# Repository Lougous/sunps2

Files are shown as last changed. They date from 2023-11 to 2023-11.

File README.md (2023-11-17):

This project allows the use of PS/2 keyboard and mouse with SUN stations fitted with proprietary 8 pins mini-DIN connector.

It is based on a PIC24FJ48GA002 microcontroller, an absolute overkill, and quite inappropriate as it cannot run under 5V power input - but I got this part in stock. I used a 74HC00 NAND gates to invert serial link signals (SUN serial protocol has negative logic) as well as 3.3V to 5V level shifter. PIC's inputs are 5V tolerant.

Resource usage in the microcontroller:
 * 2 externals interrupts
 * 1 internal timer with interrupt
 * 2 UARTs
 * a very few bytes of RAM and ~1k instructions

features and limitations:
 * keyboard layout is configured at compilation (see SUN_LAYOUT #define in main.c)
 * keyboard LED driving is not implemented
 * F12 key is mapped to SUN STOP key - handy to enter openboot prompt with STOP-A

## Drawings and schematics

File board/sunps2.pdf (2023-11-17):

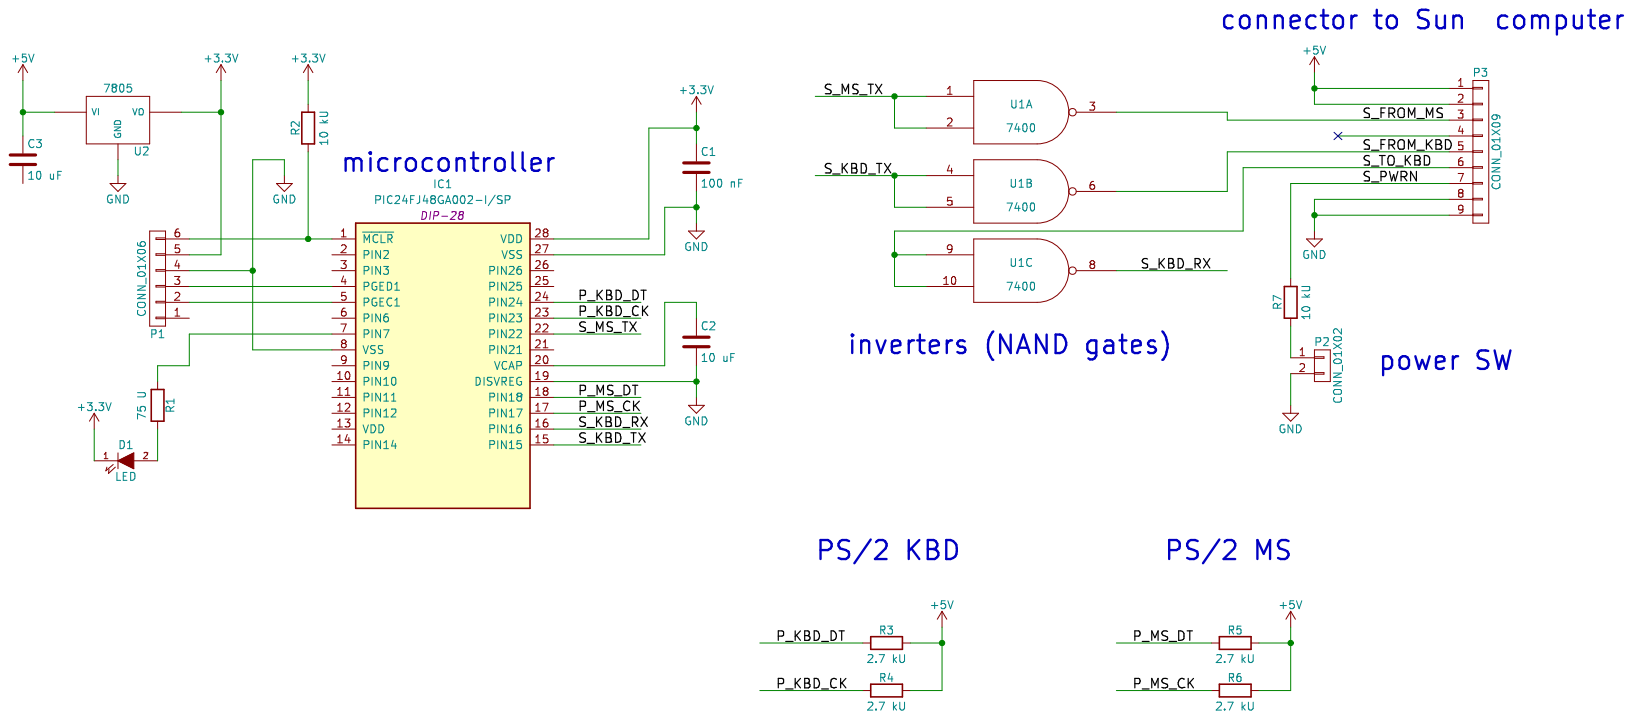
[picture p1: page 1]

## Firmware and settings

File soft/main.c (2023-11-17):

// PIC24FJ48GA002 Configuration Bit Settings

// 'C' source line config statements

// CONFIG2
#pragma config POSCMOD = NONE           // Primary Oscillator Select (Primary oscillator disabled)
#pragma config I2C1SEL = PRI            // I2C1 Pin Location Select (Use default SCL1/SDA1 pins)
#pragma config IOL1WAY = ON             // IOLOCK Protection (Once IOLOCK is set, cannot be changed)
#pragma config OSCIOFNC = OFF           // Primary Oscillator Output Function (OSC2/CLKO/RC15 functions as CLKO (FOSC/2))
#pragma config FCKSM = CSDCMD           // Clock Switching and Monitor (Clock switching and Fail-Safe Clock Monitor are disabled)
#pragma config FNOSC = FRC              // Oscillator Select (Fast RC Oscillator (FRC))
#pragma config SOSCSEL = SOSC           // Sec Oscillator Select (Default Secondary Oscillator (SOSC))
#pragma config WUTSEL = LEG             // Wake-up timer Select (Legacy Wake-up Timer)
#pragma config IESO = ON                // Internal External Switch Over Mode (IESO mode (Two-Speed Start-up) enabled)

// CONFIG1
#pragma config WDTPS = PS32768          // Watchdog Timer Postscaler (1:32,768)
#pragma config FWPSA = PR128            // WDT Prescaler (Prescaler ratio of 1:128)
#pragma config WINDIS = OFF             // Watchdog Timer Window (Standard Watchdog Timer enabled,(Windowed-mode is disabled))
#pragma config FWDTEN = OFF             // Watchdog Timer Enable (Watchdog Timer is enabled)
#pragma config ICS = PGx1               // Comm Channel Select (Emulator EMUC1/EMUD1 pins are shared with PGC1/PGD1)
#pragma config GWRP = OFF               // General Code Segment Write Protect (Writes to program memory are allowed)
#pragma config GCP = OFF                // General Code Segment Code Protect (Code protection is disabled)
#pragma config JTAGEN = OFF             // JTAG Port Enable (JTAG port is enabled)

// #pragma config statements should precede project file includes.
// Use project enums instead of #define for ON and OFF.

#include <xc.h>

#include "keymap.h"

//#define SUN_LAYOUT  0x21  // USA type 5
#define SUN_LAYOUT  0x23  // french type 5


#define FREQ       8000000UL  // 8 MHz (default configuration)
#define PS2_BAUDS  12000UL    // 10 to 16.6 kHz

volatile unsigned short kbd_dat;
volatile unsigned short kbd_sin;

// interrupt handler for external interrupt #1
void __attribute__((__interrupt__, auto_psv)) _INT1Interrupt(void)
{
	if (IFS1bits.INT1IF == 1) {
		// interrupt 1: keyboard
		kbd_sin = (((unsigned short)PORTBbits.RB13) << 15) | (kbd_sin >> 1);

        if (!(kbd_sin & 32)) {
			kbd_dat = kbd_sin;
			kbd_sin = 0xffff;
		}

		// clear interrupt
		IFS1bits.INT1IF = 0;
	}
}

volatile unsigned short ms_dat;
volatile unsigned short ms_sin;
volatile unsigned short ms_recv_mode;

// interrupt handler for external interrupt #2
void __attribute__((__interrupt__, auto_psv)) _INT2Interrupt(void)
{
	if (IFS1bits.INT2IF == 1) {
		// interrupt 2: mouse
		if (ms_recv_mode == 1) {
			// mouse => microcontroller
			ms_sin = (((unsigned short)PORTBbits.RB9) << 15) | (ms_sin >> 1);

     	    if (!(ms_sin & 32)) {
				ms_dat = ms_sin;
				ms_sin = 0xffff;
			}

		} else {
			// microcontroller => mouse
			LATBbits.LATB9 = ms_sin & 1;
			ms_sin = 0x8000 | (ms_sin >> 1);

			if (ms_sin == 0xfffe) {
				// start of STOP bit
                // data just driven to 1 for STOP bit, can now be left open
                // as it will pulled up by external resistor. the ACK bit is
                // driven by the mouse
                TRISBbits.TRISB9 = 1;  // data = input
            } else if (ms_sin == 0xffff) {
                // last clock low pulse in the transmission: ACK bit
                // ACK value could be checked here ...
                // back to receive mode
				ms_recv_mode = 1;
			}
		}

		// clear interrupt
		IFS1bits.INT2IF = 0;
	}
}

// interrupt handler for timer 1 (100 us pulse on mouse PS/2 clock))
void __attribute__((__interrupt__, auto_psv)) _T1Interrupt(void)
{
    if (IFS0bits.T1IF) {
        // drive data low (start bit)
        LATBbits.LATB9   = 0;
        TRISBbits.TRISB9 = 0;  // data = output

        // clear interrupt pending due to rts
        IFS1bits.INT2IF = 0;
    
        // release the clock
        TRISBbits.TRISB8 = 1;  // clock = input

        // enable mouse PS/2 clock interrupt
        IEC1bits.INT2IE = 1;

        // disable timer 1
        T1CON = 0x0000;
    
        // disable timer 1 interrupt
        IEC0bits.T1IE = 0;
    
        // clear timer 1 interrupt
        IFS0bits.T1IF = 0;
    }
}

// send as keyboard
void uart1_send(unsigned short txc) {
	while (U1STAbits.UTXBF == 1);

	U1TXREG = txc;
}

// send command to mouse
// bit 8 is odd parity of bits 7-0
void mouse_send(unsigned short c) {
    // disable mouse PS/2 clock interrupt, so that it won't trig when driving
    // clock low
	IEC1bits.INT2IE = 0;
    
    // prepare shift register with data to send
	ms_recv_mode = 0;
	ms_sin = (c & 0x1ff) | 0xfa00;
	
	// drive clock low (rts)
	TRISBbits.TRISB8 = 0;  // clock = output

    // prepare timer to trig an interrupt in 100 us
    PR1   = 100*(unsigned short)(FREQ/2000000UL);
    TMR1  = 0;
    IEC0bits.T1IE = 1;
	T1CON = 0x8000;  // enable, Internal clock (FOSC/2)

//
//	TRISBbits.TRISB9   = 1;  // RB9 (pin 18) is input (PS/2 data)
}

void mouse_decode(unsigned short ms_byte1,
				  unsigned short ms_byte2,
				  unsigned short ms_byte3) {
	signed short sdx, sdy;
	unsigned short dx, dy;

	// last char not fully send, abort
	if (U2STAbits.UTXBF == 1) return;

	// first char
    //     d7    d6     d5     d4     d3     d2     d1     d0
    //     1     0      0      0      0      lb     mb     rb
	//  lb (mb, rb) are cleared when the left (middle, right) button is
    //  pressed
	U2TXREG = 0x80 | ((((ms_byte1 & 1) << 2) | ((ms_byte1 & 6) >> 1)) ^ 0x07);

	// second char
    //     d7    d6     d5     d4     d3     d2     d1     d0
    //      0    dxa6   dxa5   dxa4   dxa3   dxa2   dxa1   dxa0
	// compute dx
	if (ms_byte1 & 0x40) {
		// X overflow
		if (ms_byte1 & 0x10) {
			// negative
			dx = 0x80;   // -128
		} else {
			// positive
			dx = 0x7F;   // 127
		}
	} else {
		if (ms_byte1 & 0x10) {
			// negative
			sdx = 0xff00 | ms_byte2;

			if (sdx < -128) {
				// overflow
				dx = 0x80;   // -128
			} else {
				dx = ms_byte2 & 0xff;
			}
		} else {
			// positive
			if (ms_byte2 & 0xff80) {
				// overflow
				dx = 0x7F;   // 127
			} else {
				dx = ms_byte2;
			}
		}
	}
	
	while (U2STAbits.UTXBF == 1);
	U2TXREG = dx;

	// third char
    //     d7    d6     d5     d4     d3     d2     d1     d0
    //      0    dya6   dya5   dya4   dya3   dya2   dya1   dya0
	// compute dy
	if (ms_byte1 & 0x80) {
		// X overflow
		if (ms_byte1 & 0x20) {
			// negative
			dx = 0x7F;   // 127
		} else {
			// positive
			dx = 0x80;   // -128
		}
	} else {
		if (ms_byte1 & 0x20) {
			// negative
			sdy = (0xff00 | ms_byte3);

			if (sdy < -128) {
				// overflow
				dy = 0x80;   // -128
			} else {
				dy = sdy & 0xff;
			}
		} else {
			// positive
			sdy = (0x00ff & ms_byte3);

			if (sdy & 0xff80) {
				// overflow
				dy = 0x7F;   // 127
			} else {
				dy = sdy;
			}
		}
	}
	
	while (U2STAbits.UTXBF == 1);
	U2TXREG = dy;

    // forth and fifth
	while (U2STAbits.UTXBF == 1);
	U2TXREG = 0;

	while (U2STAbits.UTXBF == 1);
	U2TXREG = 0;
}

int main (int argc, char *argv []) {
    unsigned long led_hit = 0;
    unsigned long mouse_timeout = 1000000;
	int break_mode = 0;
	int ext_mode = 0;
	unsigned short ms_byte1, ms_byte2, ms_byte3;
	typedef enum {	MS_SELF_TEST, MS_ERROR, MS_MOUSE_ID,
					MS_ACK_SAMPLE_SET, MS_ACK_SAMPLE_RATE, MS_ACK,
					MS_BYTE1, MS_BYTE2, MS_BYTE3 } ms_state_type;
	ms_state_type ms_state = MS_SELF_TEST;
    char kbd_led_mode = 0;

    ///////////////////////////////////////////////////////////////////////////
    // onchip & IO configuration
    ///////////////////////////////////////////////////////////////////////////
	// oscillator config
//    OSCCONbits.SOSCEN = 0;
	OSCCONbits.NOSC = 0; // Fast RC Oscillator

	// unlock io mapping
	// 1. Write 46h to OSCCON<7:0>.
	// 2. Write 57h to OSCCON<7:0>.
	// 3. Clear (or set) IOLOCK as a single operation

	// pinout mapping
	// disable all analog inputs
	AD1PCFG = 0xffff;

	// disable parallel master port
	PMCON = 0x0080;

	// LED: RB3 (pin 7)
	TRISBbits.TRISB3 = 0;   // output
	PORTBbits.RB3    = 0;   // GND = LED on

	// keyboard communication (bidir) with SUN
	// UART1 configuration
	RPINR18bits.U1RXR = 7;  // RX => RP7 (pin 16)
	RPOR3bits.RP6R    = 3;  // TX => RP6 (pin 15)
	U1BRG  = (((FREQ/2)/1200UL)/16) - 1;   // 1200 bauds
	U1MODE = 0x8000;                   // enable UART1
	U1STA  = 0x0400;                   // enable TX

	// mouse communication (TX only) with SUN
	// UART2 configuration
	RPINR19bits.U2RXR = 10;  // RX => RP10 (pin 21), not used !
	RPOR5bits.RP11R   = 5;   // TX => RP11 (pin 22)
	U2BRG  = (((FREQ/2)/1200UL)/16) - 1;   // 1200 bauds
	U2MODE = 0x8000;                   // enable UART2
	U2STA  = 0x0400;                   // enable TX

    // PS/2 keyboard capture
	// external interrupt #1 configuration (PS/2 clock)
	kbd_dat = 0xffff;
	kbd_sin = 0xffff;

    RPINR0bits.INT1R   = 12; // RP12 (pin 23)
	INTCON2bits.INT1EP = 1;  // interrupt on negative edge
	IPC5bits.INT1IP    = 1;  // priority 1
	IEC1bits.INT1IE    = 1;  // interrupt enabled

	TRISBbits.TRISB13  = 1;  // RB13 (pin 24) is input (PS/2 data)

    // PS/2 mouse capture
	// external interrupt #2 configuration (PS/2 clock)
	ms_dat = 0xffff;
	ms_sin = 0xffff;
    ms_recv_mode = 1;

    RPINR1bits.INT2R   = 8;  // RP8 (pin 17)
	INTCON2bits.INT2EP = 1;  // interrupt on negative edge
	IPC7bits.INT2IP    = 2;  // priority 2
	IEC1bits.INT2IE    = 1;  // interrupt enabled
	LATBbits.LATB8     = 0;  // always driven low (open-drain)

	TRISBbits.TRISB9   = 1;  // RB9 (pin 18) is input (PS/2 data)

    ///////////////////////////////////////////////////////////////////////////
    // Main loop
    ///////////////////////////////////////////////////////////////////////////
	while (1) {
		if (U1STAbits.URXDA) {
			// word received from SUN as keyboard command
			unsigned short rxc = U1RXREG;

			// turn LED off for a while
			PORTBbits.RB3 = 1;     // VCC = LED off
			led_hit       = 100000;

            if (kbd_led_mode) {
                kbd_led_mode = 0;
                
                // TODO
            } else {
                switch (rxc) {
                case 0x01:
                    // reset command
                    uart1_send(0xff);
                    uart1_send(0x04);
                    uart1_send(0x7f);
                    break;

                case 0x02:  // bell ON
                case 0x03:  // bell OFF
                case 0x0A:  // click ON
                case 0x0B:  // click OFF
                    // ignore
                    break;

                case 0x0E:  // LED
                    kbd_led_mode = 1;
                    break;

                case 0x0F:
                    // layout command
                    uart1_send(0xfe);
                    uart1_send(SUN_LAYOUT);
                    break;

                default:
                    led_hit = 1000000;
                    break;
                }
            }
		}

        if (!(kbd_dat & 32)) {
			// 11 bits read from PS/2 keyboard
			// ignore parity and stop bit
			unsigned short rxc = (kbd_dat >> 6) & 255;

			// reset receiving buffer
			kbd_dat = 0xffff;

			// turn LED off for a while
			PORTBbits.RB3 = 1;     // VCC = LED off
			led_hit       = 5000;
            unsigned char to_send = 0;
            
			if (break_mode) {
				if (ext_mode) {
					if (ps2_ext_to_sun_tbl[rxc & 0x7f]) {
						to_send = 0x80 | ps2_ext_to_sun_tbl[rxc & 0x7f];
					}
					
					break_mode = 0;
					ext_mode = 0;
				} else {
					if (ps2_to_sun_tbl[rxc & 0x7f]) {
						to_send = 0x80 | ps2_to_sun_tbl[rxc & 0x7f];
					}
				}

				break_mode = 0;
				ext_mode = 0;
		 	} else if (ext_mode) {
				if (rxc == 0xF0) {
					break_mode = 1;
				} else {
					if (ps2_ext_to_sun_tbl[rxc & 0x7f]) {
						to_send = ps2_ext_to_sun_tbl[rxc & 0x7f];
					}
					
					break_mode = 0;
					ext_mode = 0;
				}
			} else {
				if (rxc == 0xE0) {
					ext_mode = 1;
				} else if (rxc == 0xF0) {
					break_mode = 1;
				} else {
					if (ps2_to_sun_tbl[rxc & 0x7f]) {
						to_send = ps2_to_sun_tbl[rxc & 0x7f];
					}
				}
			}
            
            if (to_send) {
                uart1_send(to_send);
            }
		}

		// mouse handler
        if (!(ms_dat & 32)) {
            
            mouse_timeout = 1000000;
            
			// 11 bits read from PS/2 mouse
			// ignore parity and stop bit
			unsigned short rxc = (ms_dat >> 6) & 255;

			// reset receiving buffer
			ms_dat = 0xffff;

			switch (ms_state) {
			case MS_SELF_TEST:
			case MS_ERROR:
				if (rxc == 0xAA) {
					ms_state = MS_MOUSE_ID;
				} else {
					ms_state = MS_ERROR;
				}
				break;

			case MS_MOUSE_ID:
				// mouse ID received
				// send "enable device"
				mouse_send(0x1F3);
				ms_state = MS_ACK_SAMPLE_SET;
				break;

			case MS_ACK_SAMPLE_SET:
				if (rxc == 0xFA) {
					mouse_send(0x114);   // 20 samples/s
					ms_state = MS_ACK_SAMPLE_RATE;
				} else {
					ms_state = MS_ERROR;
				}
				break;

			case MS_ACK_SAMPLE_RATE:
				if (rxc == 0xFA) {
					mouse_send(0x0F4);   // Enable data reporting
					ms_state = MS_ACK;
				} else {
					ms_state = MS_ERROR;
				}
				break;

			case MS_ACK:
				if (rxc == 0xFA) {
					ms_state = MS_BYTE1;
				} else {
					ms_state = MS_ERROR;
				}
				break;

			case MS_BYTE1:
				ms_byte1 = rxc;
				ms_state = MS_BYTE2;
				break;

			case MS_BYTE2:
				ms_byte2 = rxc;
				ms_state = MS_BYTE3;
				break;

			case MS_BYTE3:
				ms_byte3 = rxc;
				ms_state = MS_BYTE1;

				mouse_decode(ms_byte1, ms_byte2, ms_byte3);
				break;

			default:
				break;
			}
		}

		if (led_hit == 0) {
			PORTBbits.RB3    = 0;  // GND = LED on
		} else {
			led_hit--;
		}
        
        if (mouse_timeout == 0) {
            mouse_timeout = 200000;
            
            ms_state = MS_SELF_TEST;
            mouse_send(0x1FF);   // self test
        } else {
            mouse_timeout--;
        }

		// mouse error: half bright
		if (ms_state == MS_ERROR && led_hit == 0) {
			led_hit = 1;
		}
	}

	return 0;
}
